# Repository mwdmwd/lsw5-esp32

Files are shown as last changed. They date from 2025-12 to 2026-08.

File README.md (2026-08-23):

# lsw5-esp32

> ESP32-based replacement PCB for the Deye/Sofar/Igen/Solarman/... LSW-5 *Stick Logger* with RS-485 CT meter emulation

This is a replacement ESP32-S3 daughterboard for the "LSW-5" *Stick Logger* (FCC ID [2A4FRLSW-5](https://fccid.io/2A4FRLSW-5)).

It replaces the original board, which is based on a [Hi-Flying HF-LPT270](http://www.hi-flying.com/hf-lpt270) [^lpt270] ([BL602](https://en.bouffalolab.com/product/?type=detail&id=1) inside[^lpt270-why-not]). With an ESP32-S3, it enables ESPHome support while keeping the *Stick Logger*'s modern, minimalistic appearance intact[^rs485-hole].

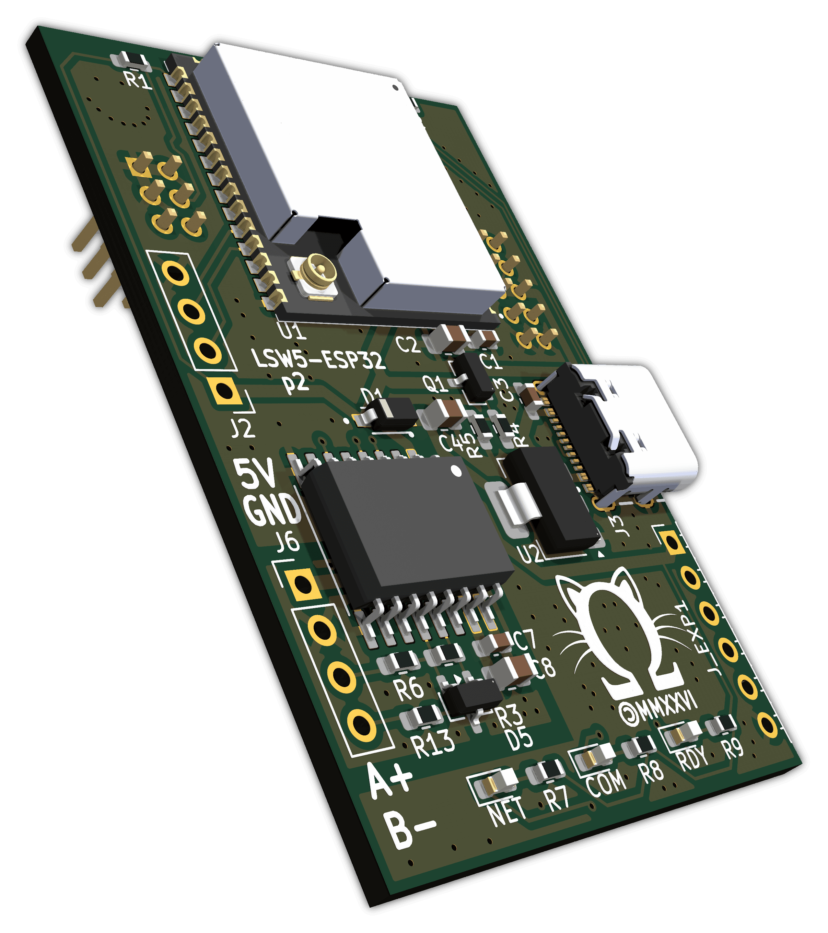
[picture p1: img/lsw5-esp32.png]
Render


## Compatibility

* **Target Device**: LSW-5 *Stick Logger*, FCC ID: [2A4FRLSW-5](https://fccid.io/2A4FRLSW-5) and others (for example, mine, which does not have an FCC ID printed on it). May also fit the [2BC8DLSW-5](https://fccid.io/2BC8DLSW-5) (not verified, no internal photos), or other types of *Stick Logger*.
  * If your *Stick Logger* looks similar to the FCC photos, this board may fit regardless of whether the inverter-side connector is USB, DB-9, or the round 4-pin type.
* **Connection**: This board replaces the internal daughterboard connected via two (2x3, 2x5) socketed 2 mm pin headers.

## Features

* **ESP32-S3** (WROOM-1U-N16R8) with WiFi, BLE and a USB-C port for flashing/debugging.
* Works with **ESPHome**.
* 2.54 mm **expansion header** with 4 GPIOs with no predetermined function. Add a temperature sensor, I²C display, or any peripheral supported by ESPHome (or any other software you choose to run).
* **Open source hardware** designed in KiCad.
* Isolated **RS-485** transceiver for meter emulation.
  * Requires external 5V supply, as available from the *Meter-485* port in (some?) Deye hybrid inverters. Or use a phone charger to power it.[^rs485-isolation]
  * One isolated RS-485 port is present, but it could *potentially* be used for both meter emulation and BMS communication by connecting those to the same bus and configuring addresses appropriately; the Deye DSP firmware is hardcoded to use `1` for the "external CT" meter and `2` for the "Grid Tie Meter2" so these addresses are not available for BMS use. Unsure about address `0`.
    * You could definitely choose to use it *only* for BMS communication, with projects like [esphome-jk-bms](https://github.com/syssi/esphome-jk-bms)
* **LEDs**: on-board status LEDs (NET, RDY, COM) matching the translucent windows in the stock case mapped to ESP32 GPIOs.

## Hardware

The design files (schematics and PCB layout) are available in this repository.

### Pinout

| Function | ESP32 pin | Location | Remarks |
| :--- | :--- | :--- | :--- |
| **3.3V input** from carrier board | `3V3` | J4 pins 5, 6 | |
| **GND** from carrier board | `GND` | J1 pins 1, 2, 3; J4 pins 9, 10 | |
| | | | |
| **RX from inverter** (RS232 [^rs232])  | `GPIO16` | J4 pin 8 | |
| **TX to inverter** (RS232) | `GPIO17` | J4 pin 7 | |
| **RX from RS485** | `GPIO21` | onboard | |
| **TX to RS485** | `GPIO48` | onboard | |
| **DE to RS485** | `GPIO47` | onboard | |
| | | | |
| **ESP32 boot mode** | `GPIO0` | J1 pin 4 | Connected to GND by the momentary switch on the bottom of the carrier board |
| **RX(?) from SIM card slot** | `GPIO5` | J4 pin 1 | Slot is not populated on the carrier board, can use as GPIO |
| **TX(?) from SIM card slot** | `GPIO4` | J4 pin 4 | Slot is not populated on the carrier board, can use as GPIO |
| | | | |
| **NET** LED | `GPIO40` | onboard | Active low |
| **COM** LED | `GPIO38` | onboard | Active low |
| **RDY** LED | `GPIO39` | onboard | Active low |
| | | | |
| **Programming port**[^usbc] 3.3V input | `3V3` | J2 pin 1 | |
| **TX to external UART programmer** | `TXD0` / `GPIO43` | J2 pin 2 | Mind the startup messages |
| **RX from external UART programmer** | `RXD0` / `GPIO44` | J2 pin 3 | |
| **GND** | `GND` | J2 pin 4 | |
| | | | |
| **Expansion port:** 3.3V | `3V3` | J_EXP1 pin 1 | |
| Unassigned | `GPIO9` | J_EXP1 pin 2 | |
| Unassigned | `GPIO10` | J_EXP1 pin 3 | |
| Unassigned | `GPIO11` | J_EXP1 pin 4 | |
| Unassigned | `GPIO12` | J_EXP1 pin 5 | |
| GND | `GND` | J_EXP1 pin 6 | |
| | | | |
| **5V input** for RS485 transceiver | | J6 pin 1 | |
| **GND** for RS485 transceiver | | J6 pin 2 | |
| RS485 **A/+** | | J6 pin 3 | |
| RS485 **B/-** | | J6 pin 4 | |

There are two connections to the inverter:

- `GPIO16`/`GPIO17` connect to the inverter's MCU1/HMI through the logger port using the logger carrier's RS232 transceiver.
- `GPIO21`/`GPIO48`/`GPIO47` drive this board's RS485 transceiver and connect to the inverter's separate Meter-485 port, which is handled directly by MCU2/DSP.

## Errata

Board revisions refer to manufactured Gerber releases, tagged in Git as `p0`, `p1`, etc. The current KiCad files may already contain changes for the next unreleased revision; those changes are not listed here until a board is manufactured. For example, if the schematic says `p2` but there is no `p2` tag, that revision has not been manufactured yet.

Errata are listed by the newest affected revision. Older revisions also inherit the errata listed above them. For example, a `p0` board has both the `p1` and `p0` errata.

* `p1`
  * RS485 port: GND/5V labels swapped on silkscreen
  * Carrier board pin headers: silkscreen is on the wrong side
  * R5 should be 10 kΩ, not 100 kΩ
  * COM and NET LED labels swapped on silkscreen
  * LEDs are connected backwards compared to the intended design
  * RS485 bus interface includes series resistors, changed to 0 Ω at the moment, but either way they are not in a good place for proper termination (as the 120 Ω termination resistor is *after* the series resistor, not before), so they should probably be removed completely
* `p0`
  * No revision label on silkscreen
  * Non-isolated RS485 transceiver is used

## Firmware

[ESPHome](https://github.com/esphome/esphome), I suppose? This board is compatible with various existing ESPHome configurations (sometimes requiring minor adjustments).

* **[esphome-deye-inverter](https://github.com/Lewa-Reka/esphome-deye-inverter)**: A very comprehensive configuration for Deye inverters, including probably all of the sensors and switches you could ever want.
* **[esphome-for-deye](https://github.com/klatremis/esphome-for-deye)**: The classic.
* **[Sunsynk-Home-Assistant-Dash](https://github.com/slipx06/Sunsynk-Home-Assistant-Dash/tree/main/ESPHome%20Configs)**: You'll need to adjust the UART pins.
* *[your configuration here?]*

### Example configuration for board-specific features

A sample [`esphome/lsw5-esp32.yaml`](./esphome/lsw5-esp32.yaml) file is included in this repository. It serves as a starting point, illustrating the correct pin mappings for this specific board. It includes basic MQTT setup and RS-485 configuration for external meter emulation with source data over MQTT, as well as LED support.

> [!NOTE]
> The inverter polls the RS-485 meter every 125 ms, except every 10th attempt which is delayed by 125 ms as the inverter tries to write `float32(0.0)` to register 286 on device 0xab. I have not been able to identify the reason / meaning of this.
>
> You should aim to keep the data in your emulator as fresh as possible to minimize over/undershooting of the *Zero Export to Grid* feature under meter emulation.

## License

The hardware design files are licensed under the CERN Open Hardware Licence Version 2 - Strongly Reciprocal (CERN-OHL-S-2.0). See [LICENSES/CERN-OHL-S-2.0.txt](./LICENSES/CERN-OHL-S-2.0.txt) for details.

The example ESPHome configuration is based on an Apache-2.0-licensed configuration and has been modified for this project. It is distributed under the Apache License, Version 2.0. See [LICENSES/Apache-2.0.txt](./LICENSES/Apache-2.0.txt) and [esphome/NOTICE](./esphome/NOTICE) for details.

All other supporting files and tools are licensed under the GNU General Public License Version 3 or, at your option, any later version (GPL-3.0-or-later). See [LICENSES/GPL-3.0.txt](./LICENSES/GPL-3.0.txt) for details.

> [!CAUTION]
> Please be careful with electricity, always disconnect the *Stick Logger* from the inverter before replacing its internal board, always turn off the inverter and disconnect it from all power sources before (dis)connecting the *Stick Logger*, and so on. I will not be responsible if your warranty is voided, your inverter is damaged, or you get shocked. If you are not sure about something, ask for help from someone who is qualified to work with power electronics.

----------

[^lpt270]: https://fccid.io/2ACSVHF-LPT270-0F
[^rs485-hole]: unless you decide to cut a hole in the case to route out the Meter-485 cable. Or cut a bit of the plastic around the DB-9 plug out and route it there, but there is a risk of forgetting about the additional cable and causing damage when enthusiastically removing the *Stick Logger*. Or route it through the reset button hole.
[^rs485-isolation]: Added in `p1`, the story is that it would work fine until connecting the RS-485 (then all sorts of weird stuff would happen). I had seen some noise between the `GND`s in the RS-485 port and the RS-232 port, and the fact that they are not electrically connected, so I decided to make an isolated revision. Then it turned out that with 3cb155f6de7685bc65d782d9486902e5723dc495 my p0 board works on the bench, but isolation seems to be a good idea regardless.
[^rs232]: Through the RS232 transceiver on the carrier board inside the *Stick Logger* which this board plugs into.
[^usbc]: Recommended to use the USB-C port for programming instead
[^lpt270-why-not]: The ESP32-S3 was chosen because its software development experience and ESPHome support are substantially better.

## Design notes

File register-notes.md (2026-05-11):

# Register notes
- Total PV Production (534): subtract Total Generator Production (537) to get just the Deye MPPTs' production, at least if the **GEN** port is configured as a microinverter input

## Useless or redundant registers
- Battery BMS SOC (214): duplicate of Battery SOC (588), at least in lithium mode
- Battery BMS Current (216): no decimal places
- DC Temperature (540): always reports 25 °C
- Battery Corrected Capacity (592): always(?) reports 200 Ah
- External CT (all registers), if you're using meter emulation: they just repeat what is fed into the RS485-Meter port

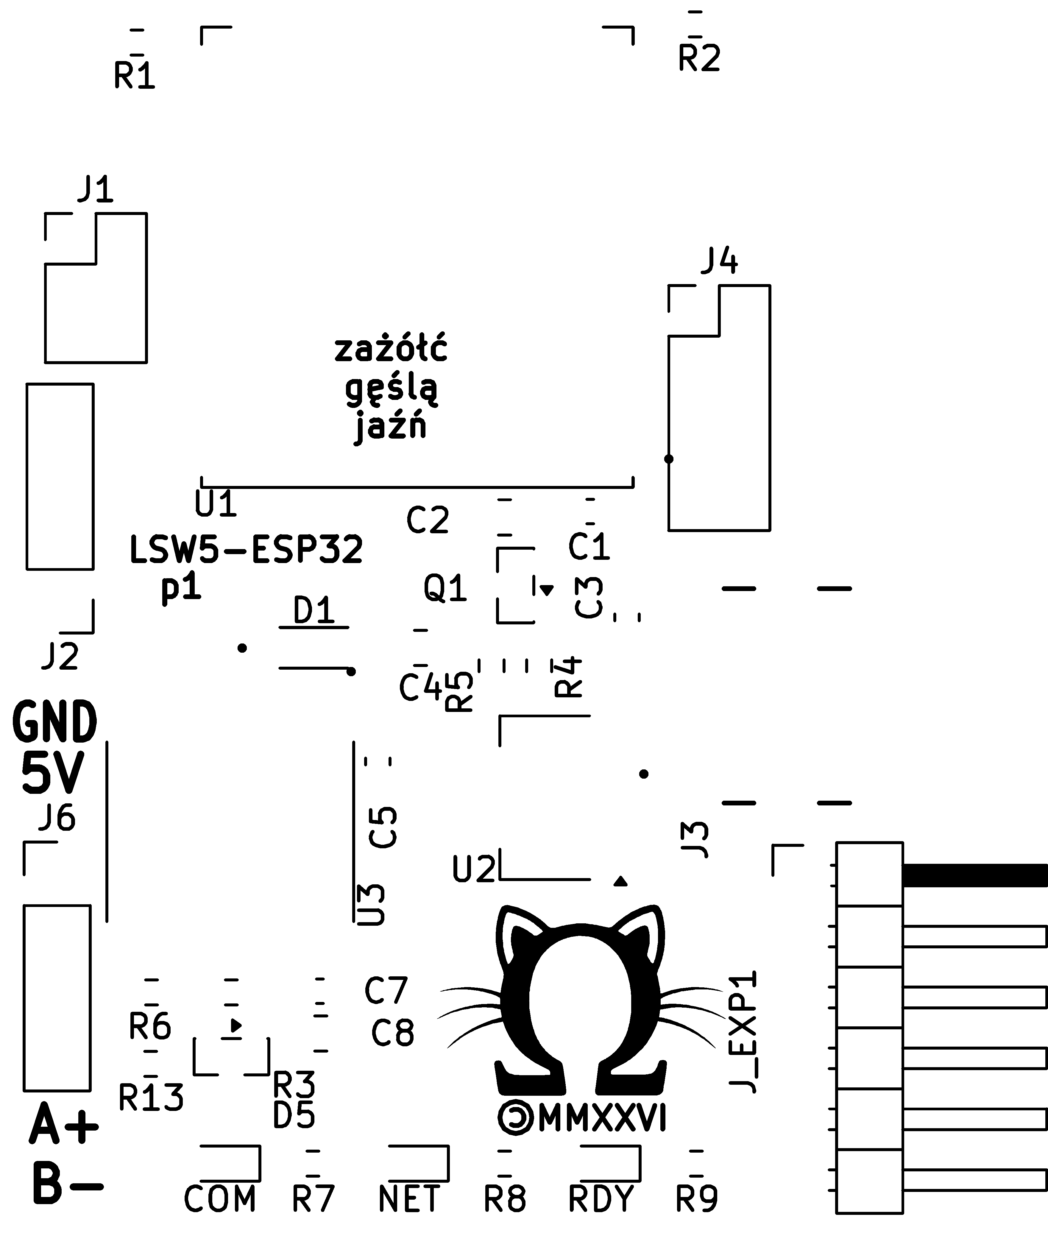
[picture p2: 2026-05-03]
SHIP/jlcpcb-00000000a_y3/yg/GBR_00000000_1_top.png

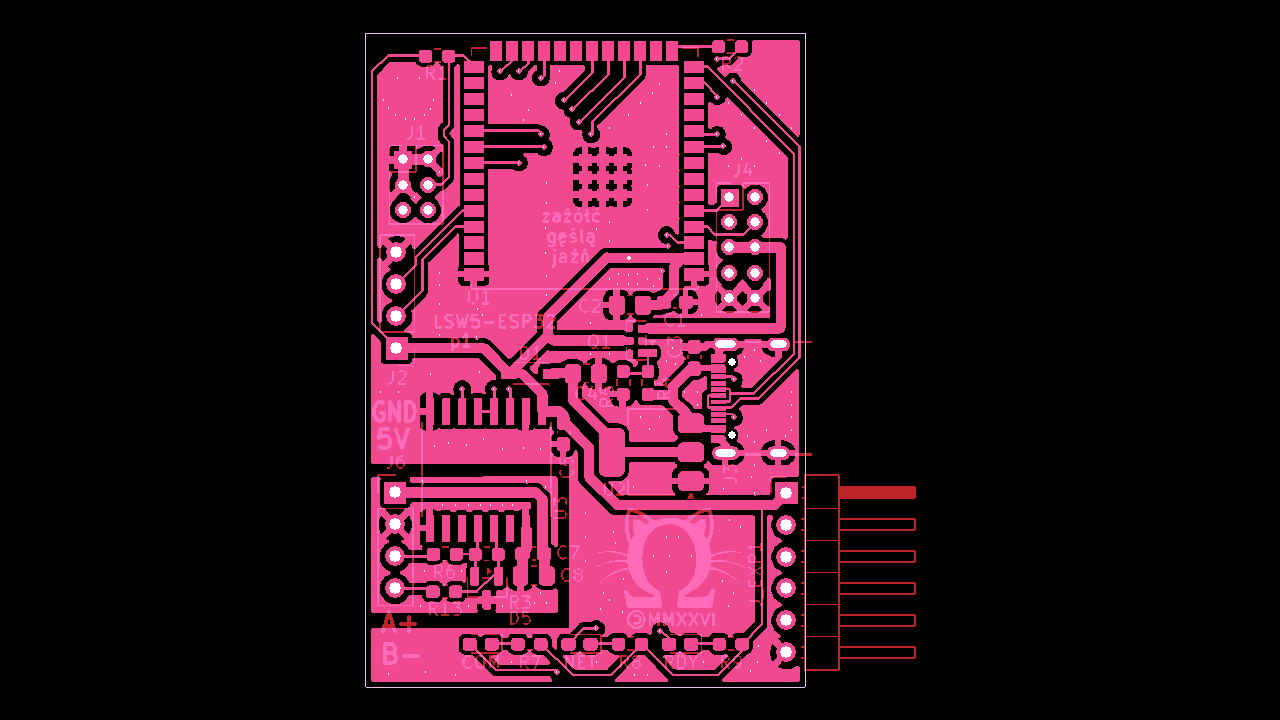
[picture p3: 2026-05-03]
SHIP/jlcpcb-00000000a_y3/yg/GBR_00000000_1_snapshot.png

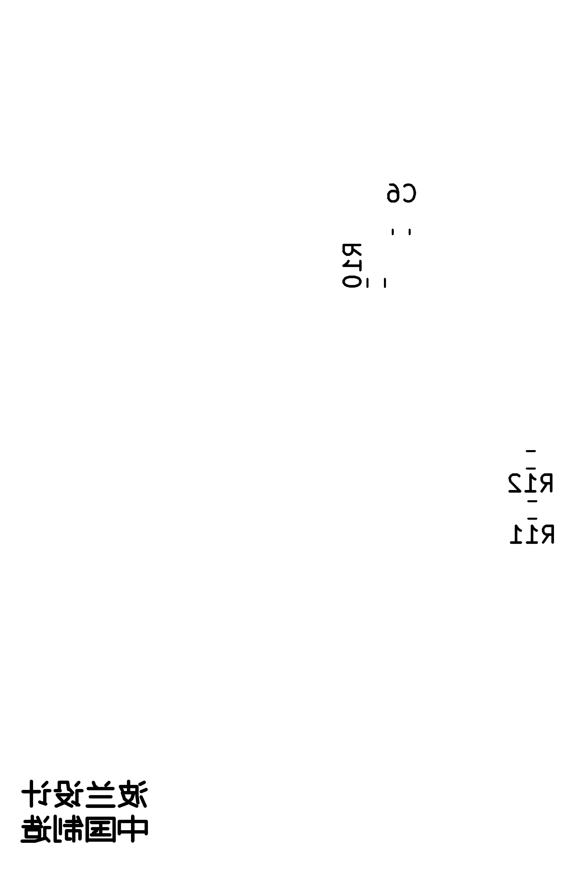
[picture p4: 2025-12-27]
SHIP/jlcpcb-00000000a_y3/yg/GBR_00000000_1_bottom.png

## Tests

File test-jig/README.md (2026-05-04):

# lsw5-esp32 test-jig

If you need this, you will know how to use it.

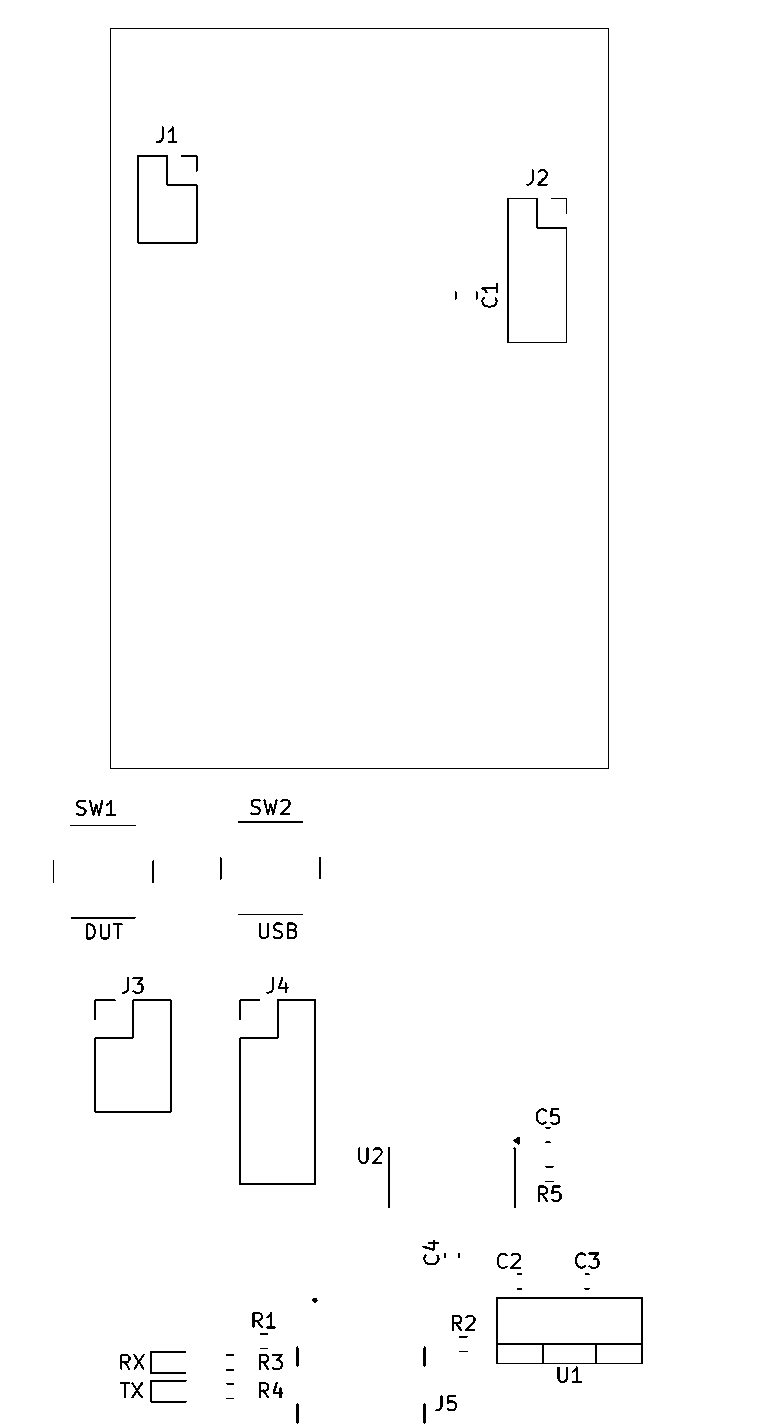
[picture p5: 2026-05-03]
test-jig/SHIP/jlcpcb-00000000a_y5/yg/GBR_00000000_1_top.png

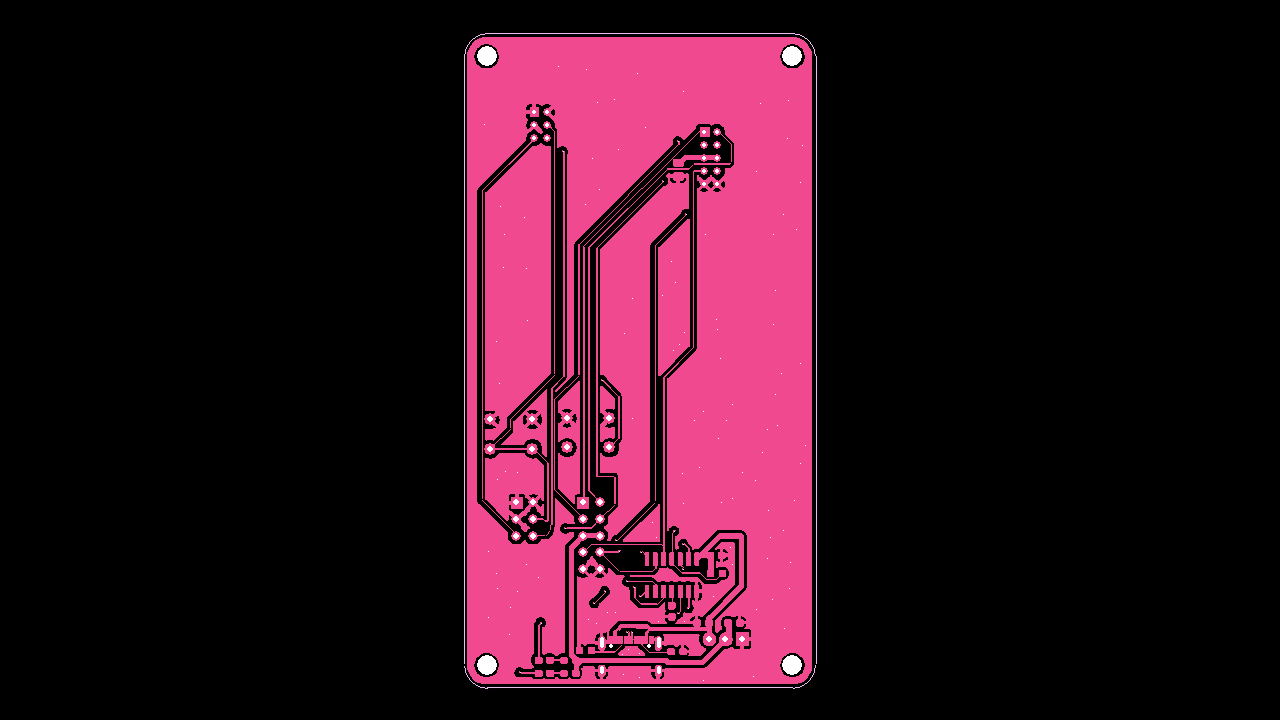
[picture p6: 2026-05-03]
test-jig/SHIP/jlcpcb-00000000a_y5/yg/GBR_00000000_1_snapshot.png

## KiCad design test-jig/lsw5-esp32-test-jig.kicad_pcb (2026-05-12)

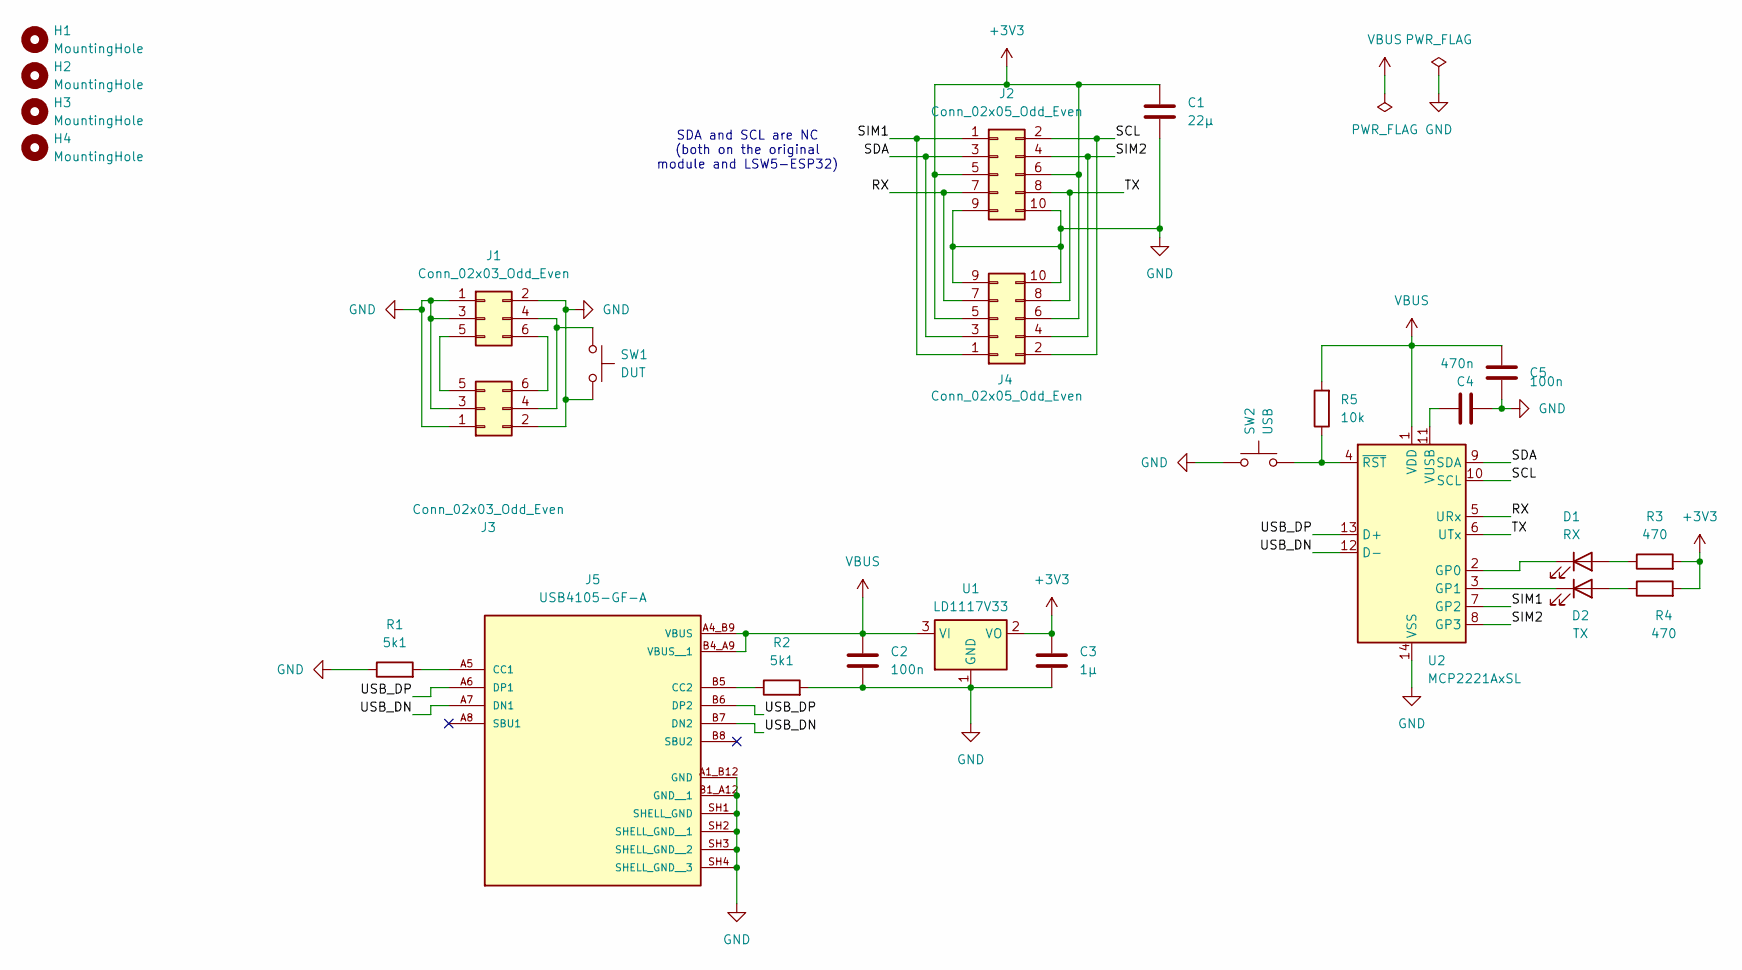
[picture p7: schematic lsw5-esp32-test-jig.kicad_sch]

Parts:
C1: 22μ; C_0805_2012Metric_Pad1.18x1.45mm_HandSolder
C2, C5: 100n; C_0603_1608Metric_Pad1.08x0.95mm_HandSolder
C3: 1μ; C_0603_1608Metric_Pad1.08x0.95mm_HandSolder
C4: 470n; C_0603_1608Metric_Pad1.08x0.95mm_HandSolder
D1: RX; LED_0603_1608Metric_Pad1.05x0.95mm_HandSolder
D2: TX; LED_0603_1608Metric_Pad1.05x0.95mm_HandSolder
H1, H2, H3, H4: MountingHole; MountingHole_3.2mm_M3
J1: Conn_02x03_Odd_Even; PinSocket_2x03_P2.00mm_Vertical
J2: Conn_02x05_Odd_Even; PinSocket_2x05_P2.00mm_Vertical
J3: Conn_02x03_Odd_Even; PinHeader_2x03_P2.54mm_Vertical
J4: Conn_02x05_Odd_Even; PinHeader_2x05_P2.54mm_Vertical
J5: USB4105-GF-A; GCT_USB4105-GF-A; PARTREV B4
R1, R2: 5k1; R_0603_1608Metric_Pad0.98x0.95mm_HandSolder
R3, R4: 470; R_0603_1608Metric_Pad0.98x0.95mm_HandSolder
R5: 10k; R_0603_1608Metric_Pad0.98x0.95mm_HandSolder
SW1: DUT; SW_PUSH_6mm
SW2: USB; SW_PUSH_6mm
U1: LD1117V33; TO-220-3_Vertical
U2: MCP2221AxSL; SOIC-14_3.9x8.7mm_P1.27mm

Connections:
+3V3: C1.1, C3.1, J2.5, J2.6, J4.5, J4.6, R3.2, R4.2, U1.2 (VO)
/RX: J2.7, J4.7, U2.5 (URx)
/SCL: J2.2, J4.2, U2.10 (SCL)
/SDA: J2.3, J4.3, U2.9 (SDA)
/SIM1: J2.1, J4.1, U2.7 (GP2)
/SIM2: J2.4, J4.4, U2.8 (GP3)
/TX: J2.8, J4.8, U2.6 (UTx)
/USB_DN: J5.A7 (DN1), J5.B7 (DN2), U2.12 (D-)
/USB_DP: J5.A6 (DP1), J5.B6 (DP2), U2.13 (D+)
GND: C1.2, C2.2, C3.2, C4.2, C5.2, J1.1, J1.2, J1.3, J2.9, J2.10, J3.1, J3.2, J3.3, J4.9, J4.10, J5.A1_B12 (GND), J5.B1_A12 (GND__1), J5.SH1 (SHELL_GND), J5.SH2 (SHELL_GND__1), J5.SH3 (SHELL_GND__2), J5.SH4 (SHELL_GND__3), R1.1, R2.2, SW1.2, SW2.1, U1.1 (GND), U2.14 (VSS)
unnamed: D1.2 (A), R3.1
unnamed: D1.1 (K), U2.2 (GP0)
unnamed: D2.2 (A), R4.1
unnamed: D2.1 (K), U2.3 (GP1)
unnamed: J1.4, J3.4, SW1.1
unnamed: J1.5, J3.5
unnamed: J1.6, J3.6
unnamed: J5.A5 (CC1), R1.2
unnamed: J5.B5 (CC2), R2.1
unnamed: C4.1, U2.11 (VUSB)
unnamed: R5.1, SW2.2, U2.4 (~RST)
VBUS: C2.1, C5.1, J5.A4_B9 (VBUS), J5.B4_A9 (VBUS__1), R5.2, U1.3 (VI), U2.1 (VDD)

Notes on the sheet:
SDA and SCL are NC (both on the original module and LSW5-ESP32)

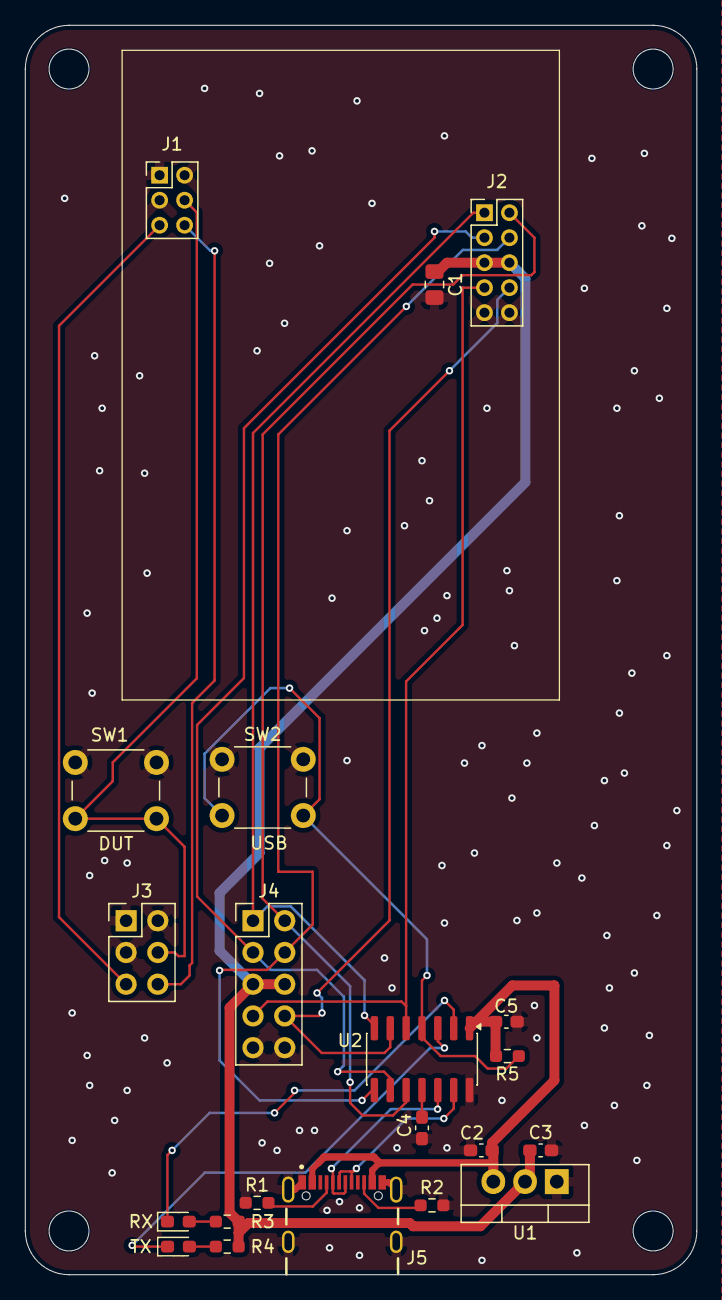
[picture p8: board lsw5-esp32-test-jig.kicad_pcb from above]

Board: 2 copper layers, 53.8 x 100.0 mm, 25 parts (0 on the bottom side), 22 nets.

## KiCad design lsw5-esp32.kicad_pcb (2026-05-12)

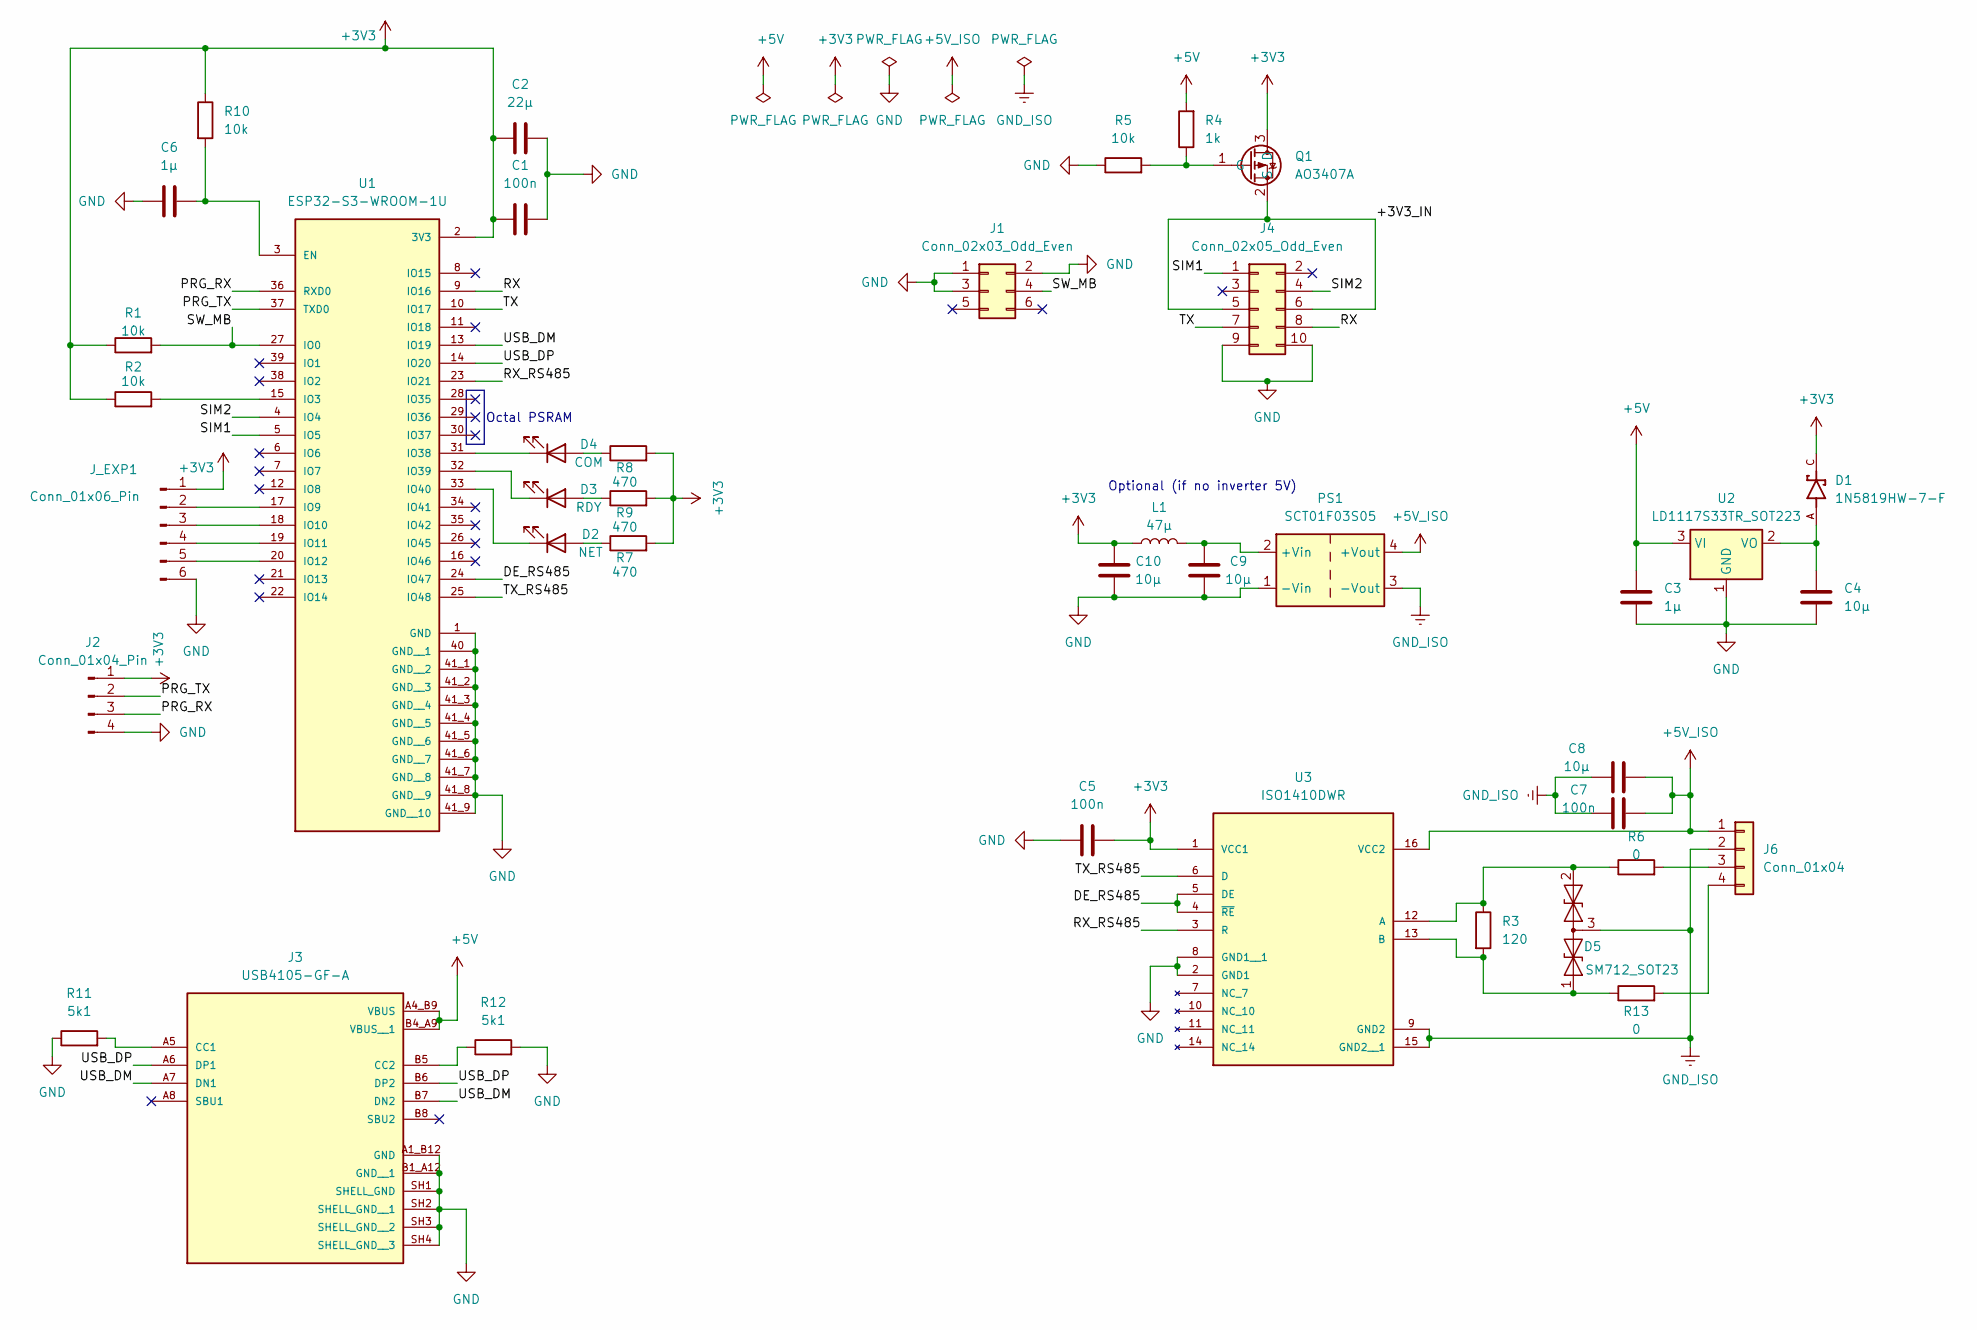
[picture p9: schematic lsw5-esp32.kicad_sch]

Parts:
C1, C5, C7: 100n; C_0603_1608Metric_Pad1.08x0.95mm_HandSolder
C2: 22μ; C_0805_2012Metric_Pad1.18x1.45mm_HandSolder
C3, C6: 1μ; C_0603_1608Metric_Pad1.08x0.95mm_HandSolder
C4, C8, C9, C10: 10μ; C_0805_2012Metric_Pad1.18x1.45mm_HandSolder
D1: 1N5819HW-7-F; SOD3715X145N; PARTREV 18-2
D2: NET; LED_0603_1608Metric_Pad1.05x0.95mm_HandSolder
D3: RDY; LED_0603_1608Metric_Pad1.05x0.95mm_HandSolder
D4: COM; LED_0603_1608Metric_Pad1.05x0.95mm_HandSolder
D5: SM712_SOT23; SOT-23
J1: Conn_02x03_Odd_Even; PinHeader_2x03_P2.00mm_Vertical
J2: Conn_01x04_Pin; PinHeader_1x04_P2.54mm_Vertical
J3: USB4105-GF-A; GCT_USB4105-GF-A; PARTREV B4
J4: Conn_02x05_Odd_Even; PinHeader_2x05_P2.00mm_Vertical
J6: Conn_01x04; PinHeader_1x04_P2.54mm_Vertical
J_EXP1: Conn_01x06_Pin; PinHeader_1x06_P2.54mm_Horizontal
L1: 47μ; L_Ferrocore_DJNR-4018
PS1: SCT01F03S05; Converter_DCDC_Murata_MEE1SxxxxSC_THT
Q1: AO3407A; SOT-23
R1, R2, R5, R10: 10k; R_0603_1608Metric_Pad0.98x0.95mm_HandSolder
R3: 120; R_0603_1608Metric_Pad0.98x0.95mm_HandSolder
R4: 1k; R_0603_1608Metric_Pad0.98x0.95mm_HandSolder
R6, R13: 0; R_0603_1608Metric_Pad0.98x0.95mm_HandSolder
R7, R8, R9: 470; R_0603_1608Metric_Pad0.98x0.95mm_HandSolder
R11, R12: 5k1; R_0603_1608Metric_Pad0.98x0.95mm_HandSolder
U1: ESP32-S3-WROOM-1U; ESP32-S3-WROOM-1U-N16R8; PARTREV v1.1
U2: LD1117S33TR_SOT223; SOT-223-3_TabPin2
U3: ISO1410DWR; SOIC127P1030X265-16N; PARTREV H

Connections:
+3V3: C1.1, C2.1, C5.1, C10.2, D1.C, J2.1, J_EXP1.1, L1.1, Q1.3 (D), R1.1, R2.1, R7.2, R8.2, R9.2, R10.1, U1.2 (3V3), U3.1 (VCC1)
+5V: C3.2, J3.A4_B9 (VBUS), J3.B4_A9 (VBUS__1), R4.2, U2.3 (VI)
+5V_ISO: C7.1, C8.1, J6.1, PS1.4 (+Vout), U3.16 (VCC2)
/+3V3_IN: J4.5, J4.6, Q1.2 (S)
/DE_RS485: U1.24 (IO47), U3.4 (~RE), U3.5 (DE)
/PRG_RX: J2.3, U1.36 (RXD0)
/PRG_TX: J2.2, U1.37 (TXD0)
/RX: J4.8, U1.9 (IO16)
/RX_RS485: U1.23 (IO21), U3.3 (R)
/SIM1: J4.1, U1.5 (IO5)
/SIM2: J4.4, U1.4 (IO4)
/SW_MB: J1.4, R1.2, U1.27 (IO0)
/TX: J4.7, U1.10 (IO17)
/TX_RS485: U1.25 (IO48), U3.6 (D)
/USB_DM: J3.A7 (DN1), J3.B7 (DN2), U1.13 (IO19)
/USB_DP: J3.A6 (DP1), J3.B6 (DP2), U1.14 (IO20)
GND: C1.2, C2.2, C3.1, C4.1, C5.2, C6.1, C9.1, C10.1, J1.1, J1.2, J1.3, J2.4, J3.A1_B12 (GND), J3.B1_A12 (GND__1), J3.SH1 (SHELL_GND), J3.SH2 (SHELL_GND__1), J3.SH3 (SHELL_GND__2), J3.SH4 (SHELL_GND__3), J4.9, J4.10, J_EXP1.6, PS1.1 (-Vin), R5.1, R11.1, R12.2, U1.1 (GND), U1.40 (GND__1), U1.41_1 (GND__2), U1.41_2 (GND__3), U1.41_3 (GND__4), U1.41_4 (GND__5), U1.41_5 (GND__6), U1.41_6 (GND__7), U1.41_7 (GND__8), U1.41_8 (GND__9), U1.41_9 (GND__10), U2.1 (GND), U3.2 (GND1), U3.8 (GND1__1)
GND_ISO: C7.2, C8.2, D5.3 (common), J6.2, PS1.3 (-Vout), U3.9 (GND2), U3.15 (GND2__1)
unnamed: C9.2, L1.2, PS1.2 (+Vin)
unnamed: D2.2 (A), R7.1
unnamed: D2.1 (K), U1.33 (IO40)
unnamed: D3.2 (A), R9.1
unnamed: D3.1 (K), U1.32 (IO39)
unnamed: D4.2 (A), R8.1
unnamed: D4.1 (K), U1.31 (IO38)
unnamed: D5.1 (A1), R3.2, R13.1, U3.13 (B)
unnamed: D5.2 (A2), R3.1, R6.1, U3.12 (A)
unnamed: J3.A5 (CC1), R11.2
unnamed: J3.B5 (CC2), R12.1
unnamed: J6.3, R6.2
unnamed: J6.4, R13.2
unnamed: J_EXP1.2, U1.17 (IO9)
unnamed: J_EXP1.3, U1.18 (IO10)
unnamed: J_EXP1.4, U1.19 (IO11)
unnamed: J_EXP1.5, U1.20 (IO12)
unnamed: Q1.1 (G), R4.1, R5.2
unnamed: C6.2, R10.2, U1.3 (EN)
unnamed: R2.2, U1.15 (IO3)
unnamed: C4.2, D1.A, U2.2 (VO)

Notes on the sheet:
Optional (if no inverter 5V)
Octal PSRAM

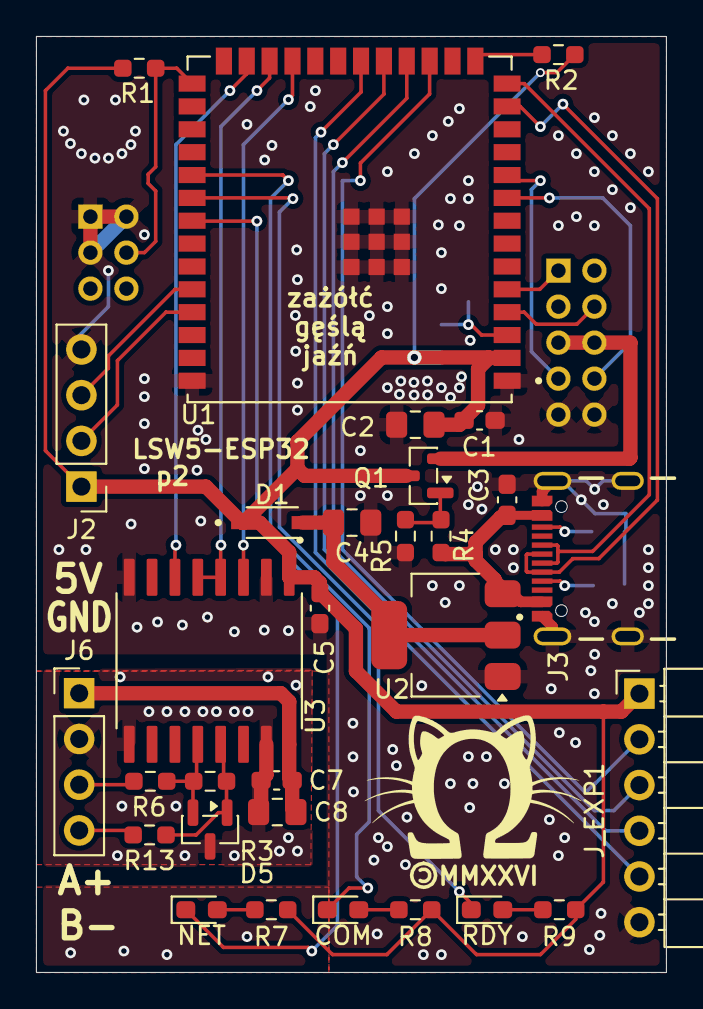
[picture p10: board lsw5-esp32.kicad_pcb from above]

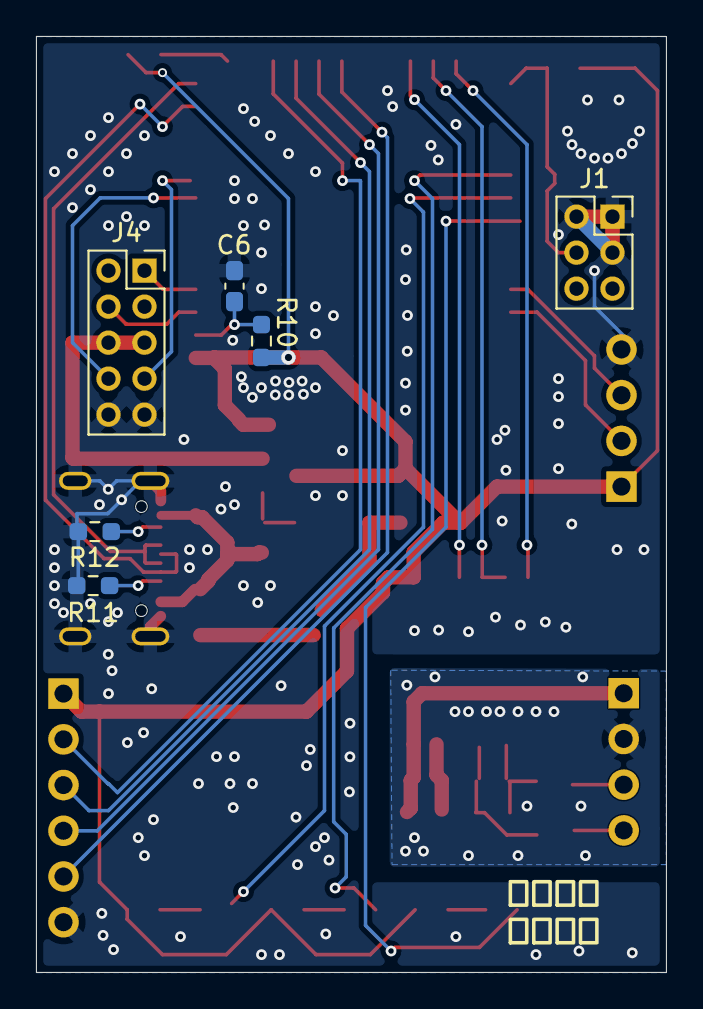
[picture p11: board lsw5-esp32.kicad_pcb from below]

Board: 2 copper layers, 35.0 x 52.0 mm, 36 parts (6 on the bottom side), 38 nets.

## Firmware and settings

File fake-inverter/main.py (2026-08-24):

#!/usr/bin/env python3
# SPDX-License-Identifier: GPL-3.0-or-later
import argparse
import logging
import random
import re
import sys
import time
from collections.abc import Iterable
from dataclasses import dataclass, field

import serial
from construct import ConstructError

from firmware_upgrade import FirmwareUpgrade
from modbus import FunctionCode, RequestFrame, ResponseFrame

LOGGER = logging.getLogger(__name__)
LOGGER_FORMAT = "%(asctime)s - %(levelname)s - %(message)s"

DEFAULT_BAUDRATE = 9600
SERIAL_TIMEOUT_SECONDS = 0.1
STATE_UPDATE_INTERVAL_SECONDS = 1.0
IDLE_SLEEP_SECONDS = 0.01
MAX_MODBUS_BUFFER_SIZE = 256
LOGGER_PREFIX = b"\xc2"
PROFILE_RANDOM = "random"
PROFILE_GENERATOR_FIRST = "generator-first"
ENERGY_TOTAL_ADDRESS = 534
ENERGY_GENERATOR_ADDRESS = 537
LOW_NOISE_MODE_ADDRESS = 35
LOW_NOISE_COMMAND_ADDRESS = 36
LOW_NOISE_COMMAND_MAGIC = 100
MCU2_PASSTHROUGH_ADDRESS = 0xAA
MAX_LOGGED_REGISTER_VALUES = 16


def clamp(value: int, minimum: int, maximum: int) -> int:
    return max(minimum, min(maximum, value))


def to_u16(value: int) -> int:
    return value & 0xFFFF


def from_s16(value: int) -> int:
    value &= 0xFFFF
    return value - 0x10000 if value >= 0x8000 else value


def words_to_bytes(registers: Iterable[int]) -> list[int]:
    data: list[int] = []
    for register in registers:
        value = to_u16(register)
        data.extend((value >> 8, value & 0xFF))
    return data


def bytes_to_words(data: Iterable[int]) -> list[int]:
    data = list(data)
    return [(data[index] << 8) | data[index + 1] for index in range(0, len(data) - 1, 2)]


def format_function(function) -> str:
    function_number = int(function)
    try:
        function_code = FunctionCode(function_number)
    except ValueError:
        return f"FC{function_number:02d} Unknown"
    function_name = re.sub(r"(?<=[a-z])(?=[A-Z])", " ", function_code.name)
    return f"FC{function_number:02d} {function_name}"


def format_register_values(start_address: int, values: Iterable[int]) -> str:
    values = list(values)
    displayed_values = values[:MAX_LOGGED_REGISTER_VALUES]
    formatted = ", ".join(
        f"r{start_address + offset}={to_u16(value)} (0x{to_u16(value):04X})"
        for offset, value in enumerate(displayed_values)
    )
    if len(values) > len(displayed_values):
        formatted += f", ... (+{len(values) - len(displayed_values)} registers)"
    return f"[{formatted}]"


def format_modbus_request(request) -> str:
    function_number = int(request.function)
    prefix = f"Modbus request: slave={request.slave_addr}, {format_function(request.function)}"

    if function_number in (
        FunctionCode.ReadHoldingRegisters,
        FunctionCode.ReadInputRegisters,
    ):
        return f"{prefix}, start={request.address}, count={request.content.nr_registers}"
    if function_number == FunctionCode.PresetSingleRegister:
        return (
            f"{prefix}, register={request.address}, "
            f"value={request.content.data} (0x{request.content.data:04X})"
        )
    if function_number == FunctionCode.PresetMultipleRegisters:
        return (
            f"{prefix}, start={request.address}, count={request.content.nr_registers}, "
            f"values={format_register_values(request.address, request.content.data)}"
        )
    return f"{prefix}, address={request.address}"


def format_modbus_response(request, response) -> str:
    function_number = int(response.function)
    prefix = f"Modbus response: slave={response.slave_addr}, {format_function(response.function)}"

    if function_number in (
        FunctionCode.ReadHoldingRegisters,
        FunctionCode.ReadInputRegisters,
    ):
        registers = bytes_to_words(response.content)
        return f"{prefix}, values={format_register_values(request.address, registers)}"
    if function_number == FunctionCode.PresetSingleRegister:
        return (
            f"{prefix}, register={response.content.address}, "
            f"value={response.content.data} (0x{response.content.data:04X}), acknowledged"
        )
    if function_number == FunctionCode.PresetMultipleRegisters:
        return (
            f"{prefix}, start={response.content.address}, "
            f"count={response.content.nr_registers}, acknowledged"
        )
    return prefix


def set_u32(registers: dict[int, int], low_word_address: int, value: int) -> None:
    registers[low_word_address] = value & 0xFFFF
    registers[low_word_address + 1] = (value >> 16) & 0xFFFF


def get_u32(registers: dict[int, int], low_word_address: int) -> int:
    return (registers.get(low_word_address + 1, 0) << 16) | registers.get(low_word_address, 0)


@dataclass
class Inverter:
    profile: str = PROFILE_RANDOM
    event_interval_seconds: float = 120.0
    catchup_delay_seconds: float = 600.0
    log_energy_reads: bool = False
    # Logger-facing MCU1 shadow and the minimal internal MCU2 state are
    # separate: raw passthrough writes do not update an immediate FC03 result.
    registers: dict[int, int] = field(default_factory=dict)
    mcu2_registers: dict[int, int] = field(default_factory=dict)
    next_event_at: float | None = None
    pending_total_catchups: list[float] = field(default_factory=list)
    firmware_upgrade: FirmwareUpgrade = field(default_factory=FirmwareUpgrade)

    def __post_init__(self) -> None:
        self.reset_registers()

    def reset_registers(self) -> None:
        self.registers = {
            0: 0x500,  # 3-phase hybrid
            1: 1,  # Modbus address
            2: 0x0102,  # Protocol version
            3: 0x3132,  # Serial number
            4: 0x3334,
            5: 0x3536,
            6: 0x3738,
            7: 0x3930,
            8: 12_000,  # Rated power
            10: 0x12,  # MCU board version
            11: 0x1234,  # Bootloader and assistant version
            12: 0x2345,  # AFCI version
            13: 0x3456,  # Slave MCU version
            14: 0x4567,  # HMI version-2
            15: 0x5678,  # HMI version
            35: 0,  # Inverter bridge FSW: 0 = 15 kHz, 1 = 20 kHz
            36: 0,  # Relay self-check status
            598: 2300,  # Grid L1 voltage, 0.1 V
            599: 2300,  # Grid L2 voltage, 0.1 V
            600: 2300,  # Grid L3 voltage, 0.1 V
            609: 5000,  # Grid frequency, 0.01 Hz
            610: 200,  # Internal CT L1 current, 0.01 A
            611: 200,
            612: 200,
            672: 1500,  # PV1 power, W
            673: 1500,  # PV2 power, W
            676: 3000,  # PV1 voltage, 0.1 V
            678: 3000,  # PV2 voltage, 0.1 V
            677: 50,  # PV1 current, 0.1 A
            679: 50,  # PV2 current, 0.1 A
            540: 40 * 10 + 1000,  # DC temperature
            541: 35 * 10 + 1000,  # AC temperature
            586: 25 * 10 + 1000,  # Battery temperature
            587: 5120,  # Battery voltage, 0.01 V
            588: 80,  # Battery SoC, %
            590: to_u16(-500),  # Battery power, W
            591: to_u16(-1000),  # Battery current, 0.01 A
            604: 200,  # Internal CT power L1, W
            605: 200,
            606: 200,
            607: 600,
            640: 500,  # UPS L1, W
            641: 500,
            642: 500,
            643: 1500,
            650: 500,  # Load L1, W
            651: 500,
            652: 500,
            653: 1500,
        }
        set_u32(self.registers, ENERGY_TOTAL_ADDRESS, 10_000)  # Total PV production, 0.1 kWh
        set_u32(
            self.registers, ENERGY_GENERATOR_ADDRESS, 10_000
        )  # Total generator production, 0.1 kWh
        self.mcu2_registers = {
            LOW_NOISE_MODE_ADDRESS: self.registers[LOW_NOISE_MODE_ADDRESS],
            LOW_NOISE_COMMAND_ADDRESS: self.registers[LOW_NOISE_COMMAND_ADDRESS],
        }

    def update(self, now: float | None = None) -> None:
        if (
            self.registers[LOW_NOISE_MODE_ADDRESS]
            != self.mcu2_registers[LOW_NOISE_MODE_ADDRESS]
        ):
            old_value = self.registers[LOW_NOISE_MODE_ADDRESS]
            self.registers[LOW_NOISE_MODE_ADDRESS] = self.mcu2_registers[LOW_NOISE_MODE_ADDRESS]
            LOGGER.info(
                "MCU1 refreshed Low Noise shadow: r35 %d -> %d",
                old_value,
                self.registers[LOW_NOISE_MODE_ADDRESS],
            )

        # Grid voltages
        for register in (598, 599, 600):
            self.registers[register] = clamp(
                self.registers[register] + random.randint(-5, 5), 2200, 2400
            )

        # Grid frequency
        self.registers[609] = clamp(self.registers[609] + random.randint(-2, 2), 4980, 5020)

        # PV power, voltage and current
        for power_register, voltage_register, current_register in (
            (672, 676, 677),
            (673, 678, 679),
        ):
            self.registers[power_register] = max(
                0, self.registers[power_register] + random.randint(-10, 10)
            )
            self.registers[voltage_register] = max(
                0, self.registers[voltage_register] + random.randint(-5, 5)
            )

            voltage = self.registers[voltage_register]
            if voltage > 0:
                self.registers[current_register] = int(
                    100 * self.registers[power_register] / voltage
                )

        # Battery power
        battery_power = clamp(from_s16(self.registers[590]) + random.randint(-20, 20), -2000, 2000)
        self.registers[590] = to_u16(battery_power)

        battery_voltage = self.registers[587] / 100.0
        if battery_voltage > 0:
            # Battery current
            self.registers[591] = to_u16(int(battery_power * 100 / battery_voltage))

        if self.profile == PROFILE_RANDOM:
            self.update_random_energy()
        elif self.profile == PROFILE_GENERATOR_FIRST:
            self.update_generator_first_energy(time.monotonic() if now is None else now)
        else:
            raise ValueError(f"Unsupported inverter profile: {self.profile}")

    def update_random_energy(self) -> None:
        # Total PV production
        if random.random() > 0.9:
            set_u32(
                self.registers,
                ENERGY_TOTAL_ADDRESS,
                get_u32(self.registers, ENERGY_TOTAL_ADDRESS) + 1,
            )

        # Total generator production
        if random.random() > 0.95:
            set_u32(
                self.registers,
                ENERGY_GENERATOR_ADDRESS,
                get_u32(self.registers, ENERGY_GENERATOR_ADDRESS) + 1,
            )

    def update_generator_first_energy(self, now: float) -> None:
        if self.next_event_at is None:
            self.next_event_at = now + self.event_interval_seconds

        while now >= self.next_event_at:
            generator_raw = get_u32(self.registers, ENERGY_GENERATOR_ADDRESS) + 1
            set_u32(self.registers, ENERGY_GENERATOR_ADDRESS, generator_raw)
            self.pending_total_catchups.append(self.next_event_at + self.catchup_delay_seconds)
            LOGGER.info(
                "Profile event: generator_raw=%d total_raw=%d catchup_due_in=%.1fs",
                generator_raw,
                get_u32(self.registers, ENERGY_TOTAL_ADDRESS),
                self.catchup_delay_seconds,
            )
            self.next_event_at += self.event_interval_seconds

        due_count = sum(1 for due_at in self.pending_total_catchups if due_at <= now)
        if due_count:
            total_raw = get_u32(self.registers, ENERGY_TOTAL_ADDRESS) + due_count
            set_u32(self.registers, ENERGY_TOTAL_ADDRESS, total_raw)
            self.pending_total_catchups = [
                due_at for due_at in self.pending_total_catchups if due_at > now
            ]
            LOGGER.info(
                "Profile catchup: total_raw=%d generator_raw=%d corrected_raw=%d",
                total_raw,
                get_u32(self.registers, ENERGY_GENERATOR_ADDRESS),
                total_raw - get_u32(self.registers, ENERGY_GENERATOR_ADDRESS),
            )

    def read_holding_registers(self, start_address: int, count: int) -> list[int]:
        if (
            self.log_energy_reads
            and start_address < ENERGY_GENERATOR_ADDRESS + 2
            and start_address + count > ENERGY_TOTAL_ADDRESS
        ):
            total_raw = get_u32(self.registers, ENERGY_TOTAL_ADDRESS)
            generator_raw = get_u32(self.registers, ENERGY_GENERATOR_ADDRESS)
            LOGGER.info(
                "Energy read: addr=%d count=%d total_raw=%d generator_raw=%d corrected_raw=%d",
                start_address,
                count,
                total_raw,
                generator_raw,
                total_raw - generator_raw,
            )
        return [self.registers.get(start_address + offset, 0) for offset in range(count)]

    def write_holding_registers(self, start_address: int, values: Iterable[int]) -> None:
        values = list(values)

        # MCU1 has no write handlers for r35/r36. It still ACKs the logger's
        # FC16 request, but its later reconstructed MCU2 write uses the
        # unchanged cache values rather than the received command payload.
        for offset, value in enumerate(values):
            address = start_address + offset
            if address in (LOW_NOISE_MODE_ADDRESS, LOW_NOISE_COMMAND_ADDRESS):
                continue
            self.registers[address] = to_u16(value)
        if start_address == 1080 and len(values) == 2 and values[1] == 0x60:
            self.firmware_upgrade.begin(to_u16(values[0]))

    def write_mcu2_holding_registers(self, start_address: int, values: Iterable[int]) -> None:
        values = list(values)
        if (
            start_address == LOW_NOISE_MODE_ADDRESS
            and len(values) == 2
            and values[1] == LOW_NOISE_COMMAND_MAGIC
            and values[0] in (0, 1)
        ):
            old_value = self.mcu2_registers[LOW_NOISE_MODE_ADDRESS]
            self.mcu2_registers[LOW_NOISE_MODE_ADDRESS] = values[0]
            LOGGER.info(
                "MCU2 applied Low Noise command: r35 %d -> %d; " "MCU1 external shadow remains %d",
                old_value,
                values[0],
                self.registers[LOW_NOISE_MODE_ADDRESS],
            )
            return

        LOGGER.info(
            "MCU2 ignored unexpected raw write: start=%d, values=%s",
            start_address,
            format_register_values(start_address, values),
        )

    def service_firmware_upgrade(self, port: serial.Serial, now: float | None = None) -> None:
        ready = self.firmware_upgrade.poll_ready(now)
        if ready is not None:
            port.write(ready)
            LOGGER.info("Response: %s", ready.hex())


def build_response(inverter: Inverter, request) -> bytes | None:
    function_code = request.function
    response_data = {
        "function": function_code,
        "slave_addr": request.slave_addr,
    }

    if int(function_code) == FunctionCode.ReadHoldingRegisters:
        registers = inverter.read_holding_registers(request.address, request.content.nr_registers)
        response_data["content"] = words_to_bytes(registers)
    elif int(function_code) == FunctionCode.PresetMultipleRegisters:
        inverter.write_holding_registers(request.address, request.content.data)
        response_data["content"] = {
            "address": request.address,
            "nr_registers": request.content.nr_registers,
        }
    elif int(function_code) == FunctionCode.PresetSingleRegister:
        inverter.write_holding_registers(request.address, [request.content.data])
        response_data["content"] = {
            "address": request.address,
            "data": request.content.data,
        }
    else:
        LOGGER.warning("Function %s is not implemented: %s", function_code, request)
        return None

    return ResponseFrame.build({"data": {"value": response_data}})


def parse_request(buffer: bytes):
    parsed = RequestFrame.parse(buffer)
    assert parsed is not None, "Parsing should have raised ConstructError if it failed"
    frame_size = parsed.data.length + 2
    return parsed.data.value, frame_size


def find_modbus_frame_offset(buffer: bytes, inverter_addr: int) -> int | None:
    """Find a CRC-valid request after UART noise without discarding it bytewise."""
    for offset in range(1, len(buffer)):
        if buffer[offset] not in (inverter_addr, 0xA2, MCU2_PASSTHROUGH_ADDRESS):
            continue
        if offset + 1 >= len(buffer) or buffer[offset + 1] not in (
            FunctionCode.ReadHoldingRegisters,
            FunctionCode.PresetSingleRegister,
            FunctionCode.PresetMultipleRegisters,
        ):
            continue
        try:
            parse_request(buffer[offset:])
        except ConstructError:
            continue
        return offset
    return None


def process_buffer(inverter: Inverter, port: serial.Serial, buffer: bytes) -> bytes:
    while buffer:
        if inverter.firmware_upgrade.active:
            buffer, replies = inverter.firmware_upgrade.consume(buffer)
            for reply in replies:
                port.write(reply)
            if inverter.firmware_upgrade.active or not buffer:
                return buffer

        buffer = buffer.lstrip(LOGGER_PREFIX)
        if not buffer:
            return buffer

        if len(buffer) < 4:
            return buffer

        try:
            request, frame_size = parse_request(buffer)
        except ConstructError:
            if len(buffer) > MAX_MODBUS_BUFFER_SIZE:
                frame_offset = find_modbus_frame_offset(buffer, inverter.registers.get(1, 1))
                discard_size = (
                    frame_offset
                    if frame_offset is not None
                    else len(buffer) - MAX_MODBUS_BUFFER_SIZE
                )
                LOGGER.warning("Discarding %d bytes from oversized garbage buffer", discard_size)
                buffer = buffer[discard_size:]
                continue
            return buffer

        request_frame = buffer[:frame_size]
        if request.slave_addr == MCU2_PASSTHROUGH_ADDRESS:
            LOGGER.info("HMI to MCU2 passthrough request: %s", format_modbus_request(request))
            LOGGER.debug("HMI to MCU2 passthrough request raw: %s", request_frame.hex(" "))
            # echo
            port.write(request_frame)
            if int(request.function) == FunctionCode.PresetMultipleRegisters:
                inverter.write_mcu2_holding_registers(request.address, request.content.data)
            buffer = buffer[frame_size:]
            continue

        LOGGER.info(format_modbus_request(request))
        LOGGER.debug("Modbus request raw: %s", request_frame.hex(" "))
        response = build_response(inverter, request)
        if response is not None:
            port.write(response)
            parsed_response = ResponseFrame.parse(response).data.value
            LOGGER.info(format_modbus_response(request, parsed_response))
            LOGGER.debug("Modbus response raw: %s", response.hex(" "))

        buffer = buffer[frame_size:]

    return buffer


def run_emulator(
    port_name: str,
    baudrate: int = DEFAULT_BAUDRATE,
    profile: str = PROFILE_RANDOM,
    event_interval_seconds: float = 120.0,
    catchup_delay_seconds: float = 600.0,
    log_energy_reads: bool = False,
) -> None:
    LOGGER.info("Starting fake inverter on %s at %d bps", port_name, baudrate)

    inverter = Inverter(
        profile=profile,
        event_interval_seconds=event_interval_seconds,
        catchup_delay_seconds=catchup_delay_seconds,
        log_energy_reads=log_energy_reads,
    )

    try:
        with serial.Serial(port_name, baudrate, timeout=SERIAL_TIMEOUT_SECONDS) as port:
            buffer = b""
            last_update = time.monotonic()

            while True:
                now = time.monotonic()
                if now - last_update >= STATE_UPDATE_INTERVAL_SECONDS:
                    inverter.update(now)
                    last_update = now

                inverter.service_firmware_upgrade(port, now)

                if not port.in_waiting:
                    time.sleep(IDLE_SLEEP_SECONDS)
                    continue

                buffer += port.read(port.in_waiting)
                buffer = process_buffer(inverter, port, buffer)
    except KeyboardInterrupt:
        LOGGER.info("Stopping fake inverter")
    except serial.SerialException as err:
        LOGGER.error("Failed to use serial port %s: %s", port_name, err)


def parse_args(argv: list[str]) -> argparse.Namespace:
    parser = argparse.ArgumentParser(description=__doc__)
    parser.add_argument("port", help="Serial port, for example /dev/ttyUSB0")
    parser.add_argument("--baud", type=int, default=DEFAULT_BAUDRATE, help="Serial baud rate")
    parser.add_argument(
        "--profile",
        choices=(PROFILE_RANDOM, PROFILE_GENERATOR_FIRST),
        default=PROFILE_RANDOM,
        help=(
            "Energy register behavior. 'generator-first' increments register 537 before "
            "register 534 catches up."
        ),
    )
    parser.add_argument(
        "--event-interval",
        type=float,
        default=120.0,
        help="Seconds between generator-first profile events",
    )
    parser.add_argument(
        "--catchup-delay",
        type=float,
        default=600.0,
        help="Seconds before total production catches up after a generator-first event",
    )
    parser.add_argument(
        "--log-energy-reads",
        action="store_true",
        help="Log returned raw energy counters whenever registers 534/537 are read",
    )
    parser.add_argument(
        "--debug",
        action="store_true",
        help="Include raw Modbus request and response frames in the logs",
    )
    return parser.parse_args(argv)
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

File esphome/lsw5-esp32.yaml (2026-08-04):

# ----------------------------------------------------------------------------
# lsw5-esp32 example configuration
#
# Portions of this file are adapted from the esphome-deye-inverter project,
# including Deye SG0XLP3 Modbus register mappings, value formats, and related
# sensor definitions.
#
# This file has been modified for the lsw5-esp32 hardware and installation
# model, including pin assignments, UART setup, MQTT inputs, and
# RS-485 support.
#
# See LICENSE in this directory for the Apache License, Version 2.0.
# See NOTICE in this directory for attribution notices.
#
# You are hereby advised that this configuration has a few strange aspects for
# historical reasons, and it will probably require adjustments to make it work
# for your needs.
# ----------------------------------------------------------------------------

substitutions:
  name: inverter
  friendly_name: Inverter
  modbus_controller_id: inverter_modbus_controller
  meter_mqtt_input_timeout: 30s
  # The Modbus controller runs every 5 seconds. Skipping 11 update cycles polls
  # slow-changing settings and cumulative counters once per minute instead.
  slow_modbus_skip_updates: "11"
  # ⚠️⚠️⚠️ CAUTION! UWAGA! ВНИМАНИЕ! ACHTUNG! 注意! ⚠️⚠️⚠️
  # Personal historical-accounting offset. This makes my HA energy sensor line
  # up with existing data from a different inverter. Set to 0.0 unless you are
  # me or you enjoy corrupting your long-term statistics.
  solar_production_offset_kwh: 24161.9

globals:
  # Highest Total PV Production published during this boot. Seeded from the
  # retained MQTT state topic so normal monotonic filtering does not write NVS.
  - id: total_pv_production_floor_kwh
    type: float
    restore_value: false
    initial_value: "-1.0f"

  # The PV total must not publish after boot until the retained MQTT floor has
  # been loaded, otherwise a reboot during a stale inverter window could leak a
  # lower value before the broker checkpoint arrives.
  - id: total_pv_production_floor_seeded
    type: bool
    restore_value: false
    initial_value: "false"

esphome:
  name: ${name}
  friendly_name: ${friendly_name}

  on_boot:
    priority: 100 # after network initialisation
    then:
      - lambda: |-
          #include "soc/gpio_sig_map.h"

          gpio_num_t uart_led_pin = GPIO_NUM_38; // COM LED
          int uart_num = id(inverter_uart).get_hw_serial_number();
          int signal_idx = -1;

          switch(uart_num) {
            case 0: signal_idx = U0TXD_OUT_IDX; break;
            case 1: signal_idx = U1TXD_OUT_IDX; break;
            case 2: signal_idx = U2TXD_OUT_IDX; break;
            default: ESP_LOGE("lambda", "What, UART is not hardware backed!?"); return;
          }

          gpio_reset_pin(uart_led_pin);
          gpio_set_direction(uart_led_pin, GPIO_MODE_OUTPUT);

          esp_rom_gpio_connect_out_signal(uart_led_pin, signal_idx, false, false);

          ESP_LOGI("lambda", "Mirrored UART%d to GPIO %d", uart_num, uart_led_pin);

esp32:
  board: esp32-s3-devkitc1-n16r8
  framework:
    type: esp-idf

psram:
  mode: octal

# Enable logging
logger:
  logs:
    modbus_controller: INFO
    modbus_controller.sensor: INFO
    modbus.number: INFO # why isn't it called modbus_controller.number xd
    modbus: INFO
    modbus_server: INFO
    sensor: INFO
    number: INFO
    switch: INFO

# Enable Home Assistant API
api:
  reboot_timeout: 0s
  encryption:
    key: !secret api.key

ota:
  - platform: esphome
    password: !secret ota.password

wifi:
  ssid: !secret wifi.ssid
  password: !secret wifi.password
  fast_connect: true
  power_save_mode: none
  domain: .lan

  # Enable fallback hotspot (captive portal) in case wifi connection fails
  ap:
    ssid: "Deye"
    password: !secret ap.password

web_server:
  local: true

captive_portal:

mqtt:
  broker: 192.168.1.10
  discovery: true
  reboot_timeout: 2min
  birth_message:
    topic: ${name}/availability
    payload: online
  will_message:
    topic: ${name}/availability
    payload: offline
  on_message:
    - topic: ${name}/generated_energy
      then:
        - lambda: |-
            auto parsed = parse_number<float>(x);
            if (!parsed.has_value() || isnan(parsed.value()) || parsed.value() < 0.0f) {
              ESP_LOGW("total_pv_production", "Ignoring invalid retained Total PV Production floor: %s", x.c_str());
              return;
            }

            const float rounded = roundf(parsed.value() * 10.0f) / 10.0f;
            auto &floor = id(total_pv_production_floor_kwh);
            if (isnan(floor) || rounded > floor) {
              floor = rounded;
              ESP_LOGI("total_pv_production", "Loaded Total PV Production floor from MQTT: %.1f kWh", floor);
            }
            id(total_pv_production_floor_seeded) = true;
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

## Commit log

2025-12-27 add shipped p0
    [lsw5-esp32-B_Cu.gbl, lsw5-esp32-B_Mask.gbs, lsw5-esp32-B_Paste.gbp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]
2025-12-27 increase a few clearances
    [lsw5-esp32.kicad_pcb]
2026-05-03 Fix swapped LED labels
    [lsw5-esp32.kicad_pcb, lsw5-esp32.kicad_sch]
2026-05-03 Move RS485 transceiver off octal SPI pins
    [lsw5-esp32.kicad_pcb, lsw5-esp32.kicad_sch]
2026-05-03 Add p1 label
    [lsw5-esp32.kicad_pcb]
2026-05-03 remove net name labels
    [lsw5-esp32.kicad_sch]
2026-05-03 Fix fp path, centralise PWR_FLAG
    [lsw5-esp32.kicad_pcb, lsw5-esp32.kicad_sch]
2026-05-03 p1 isolate RS485 transceiver
    [lsw5-esp32.kicad_pcb, lsw5-esp32.kicad_sch]
2026-05-03 set title and revision
    [lsw5-esp32.kicad_pcb, lsw5-esp32.kicad_sch]
2026-05-03 add test jig
    [lsw5-esp32-test-jig.kicad_pcb, lsw5-esp32-test-jig.kicad_sch]
2026-05-03 add shipped p1
    [lsw5-esp32-B_Cu.gbl, lsw5-esp32-B_Mask.gbs, lsw5-esp32-B_Paste.gbp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]
2026-05-03 test jig: fix 2mm headers pin 1 silkscreen
    [lsw5-esp32-test-jig.kicad_pcb]
2026-05-03 test jig: Update button labels on schematic
    [lsw5-esp32-test-jig.kicad_sch]
2026-05-03 improve noise immunity of power switch
    [lsw5-esp32.kicad_pcb, lsw5-esp32.kicad_sch]
2026-05-03 Set 3D models
    [lsw5-esp32.kicad_pcb]
2026-05-03 Fix pin header footprint being on the wrong side, not that it matters for THT but to have a reasonable render
    [lsw5-esp32.kicad_pcb]
2026-05-04 Fix LED labels on silkscreen
    [lsw5-esp32.kicad_pcb, lsw5-esp32.kicad_sch]
2026-05-04 RS485 series resistors to 0Ω
    To be removed in p2? Also, putting the series resistors before the 120Ω
    termination is bad, not that any of these considerations *probably*
    matter for chassis wiring
    [lsw5-esp32.kicad_pcb, lsw5-esp32.kicad_sch]
2026-05-04 test jig: Fix MCP2221A V_USB capacitor value
    DS20005565E-page 17
    > The VUSB pin requires an external bypass capacitor
    > with a value between 0.22 and 0.47 μF (ceramic cap)
    [lsw5-esp32-test-jig.kicad_pcb, lsw5-esp32-test-jig.kicad_sch]
2026-05-04 test jig: Fix USB only working on one side
    [lsw5-esp32-test-jig.kicad_pcb, lsw5-esp32-test-jig.kicad_sch]
2026-05-04 Fix swapped 5V/GND silkscreen on RS485 port
    [lsw5-esp32.kicad_pcb]
2026-05-04 Fix backwards LED (aka silkscreen)
    [lsw5-esp32.kicad_pcb, lsw5-esp32.kicad_sch]
2026-05-04 yaml add sensors
2026-05-04 Add battery
2026-05-04 discovery for every sensor
2026-05-04 filter out 0 on PV production
2026-05-04 prevent spike on energy readout if generator sensor is not updated yet
    [lsw5-esp32.yaml]
2026-05-04 remove Battery Corrected Capacity
    [lsw5-esp32.yaml]
2026-05-04 add battery current limits
2026-05-04 Add force off grid switch
2026-05-04 add internal CT power
2026-05-04 filter out 0 temperatures
2026-05-04 Heap size → KiB
2026-05-04 ignore KiCad history
2026-05-11 exclude 2.54 mm pin headers from pos
    [lsw5-esp32.kicad_pcb]
2026-05-12 upgrade to KiCad 10 format
    [lsw5-esp32-test-jig.kicad_pcb, lsw5-esp32-test-jig.kicad_sch, lsw5-esp32.kicad_pcb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]
2026-05-12 fix some missed warnings
    [lsw5-esp32.kicad_sch]
2026-06-07 fix inverter production generator offset
    [lsw5-esp32.yaml]
2026-06-25 Actually fix Total PV Production going down when Total Generator Production updates
    [lsw5-esp32.yaml]
2026-08-02 fake-inverter: Handle low-noise mode address
    [main.py]
2026-08-03 fake-inverter: Fix low-noise write handling
    requires 0xAA passthrough
    [main.py]
2026-08-04 esphome: Add Low Noise mode toggle
    [lsw5-esp32.yaml]
2026-08-04 esphome: Skip updates for slow-changing registers
    [lsw5-esp32.yaml]
2026-08-19 fake-inverter: Fix bootloader entry delay
    MCU1-SG-Ver1001-C059: 0x0805B0A6..0x0805B0C6, ~300 ms.
    [firmware_upgrade.py]
